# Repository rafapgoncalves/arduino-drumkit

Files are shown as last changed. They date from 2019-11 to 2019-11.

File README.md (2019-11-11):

# arduino-drumkit

An Arduino Nano USB drumkit to play with, but not limited to, [Ubuntu Studio](https://ubuntustudio.org/) 18.04 and [Hydrogen](http://hydrogen-music.org/) 0.9.7.

## Getting Started

1. Download and install Eclipse C/C++. More on that [here](https://www.eclipse.org/community/eclipse_newsletter/2017/april/article4.php);
2. Clone the repository;
3. Open eclipse and create a new workspace;
4. Go to File -> Import -> General -> Existing projects into workspace;
    - Select arduino-drumkit folder and check "Search for nested projects";
    - Make sure all projects are selected and click Finish.

### Arduino

First thing to do is to adjust the code to your arduino's version. Open [arduino/src/drums/Drumkit.cpp](/arduino/src/drums/Drumkit.cpp). 
At the Drumkit constructor you will find the declaration of the sensors (`SwitchSensor` for pull-up switches and `PiezoSensor` for piezos) and keys ([instructions](/KEYS.md)) for each drum pad.

Since I'm using Arduino Nano, the project is set up with 2 switches (one for bass drum and the other for hi-hat pedal) and 8 piezos.

You can change most of the parameters in [arduino/src/Define.h](/arduino/src/Define.h).

#### General MIDI

A few adjustments may be necessary to use it as a GM-compatible instrument:

* Make sure DEBUG messages are disabled;
* Keys may vary as stated [before](/KEYS.md);
* Baud Rate may be different, probably 31250.

### Ubuntu Studio

In order to run ubuntu-studio project you are goint to need read permission on serial port. Run the program as sudo or add your user to dialout group or equivalent. Don't forget to log off and back in for the changes to take effect.

```sh
sudo usermod -a -G dialout username
```

If you want to build ubuntu-studio project yourself, you gonna need some libraries that are not installed by default.

```sh
sudo apt update
sudo apt install libgtk-3-dev libgtkmm-3.0-dev
```

### Hardware

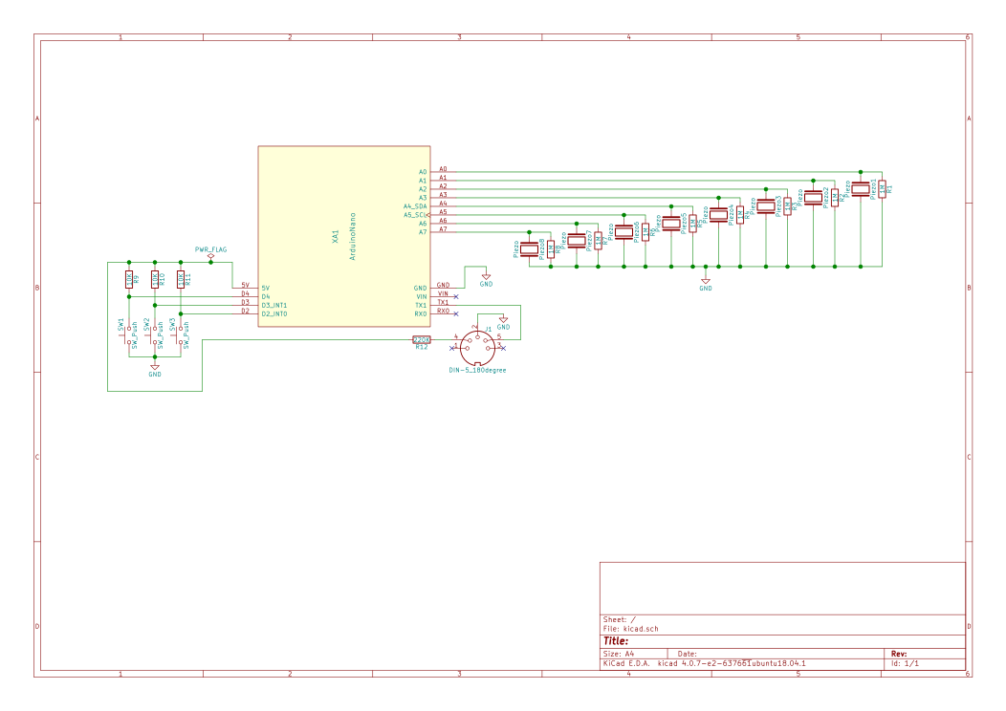
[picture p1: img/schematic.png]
Schematic


The DIN socket is optional in case you plan to use USB. And if you don't want to use USB, don't forget to add a power supply to Arduino.  

Threre is also a [KiCad](http://kicad-pcb.org/) project that you can use. This is a little bit out of scale and I didn't manage to track down where the problem is (footprint, KiCad, img conversion, etc) so double check before creating your pcb (I resized the final image). Also, your DIN socket will be different than mine.

There are good tutorials on YouTube to make drum pads such as [this](https://www.youtube.com/watch?v=-4BPpfFGcIE) one from Spikenzie.

### Jack Control

Connect your arduino to the PC, open and start ubuntu-studio project.

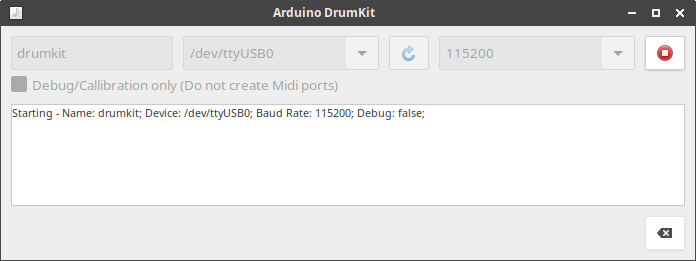
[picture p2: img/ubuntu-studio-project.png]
Ubuntu Studio Project


Open QjackCtl and Hydrogen.
On QjackCtl click the Connections button and go to ALSA tab. Connect arduino output port to hydrogen input port.

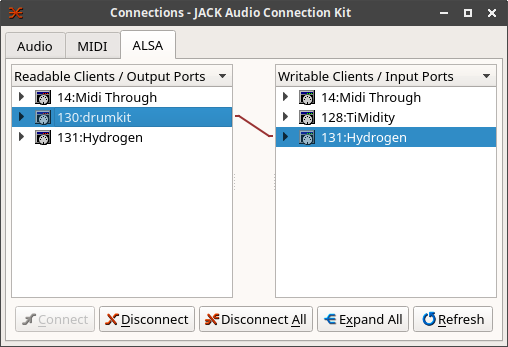
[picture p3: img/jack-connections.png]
Jack Connections


On Hydrogen, make sure input mode is set to Drumkit: Tools -> Input Mode -> Drumkit.

## License

This project is licensed under the GNU GENERAL PUBLIC LICENSE - see the [LICENSE](https://github.com/rafapgoncalves/arduino-drumkit/blob/master/LICENSE) file for details.

## Acknowledgments

* [evankale](https://github.com/evankale/ArduinoMidiDrums)
* [Dominique Vandenneucker](http://www.music-software-development.com/midi-tutorial.html)
* [amandaghassaei](https://www.instructables.com/id/Send-and-Receive-MIDI-with-Arduino/)
* [Thiago Teixeira & Jari Suominen](http://www.varal.org/ttymidi/)

## TODO

* Add MIDI Channel support
* Move debug messages to MIDI format

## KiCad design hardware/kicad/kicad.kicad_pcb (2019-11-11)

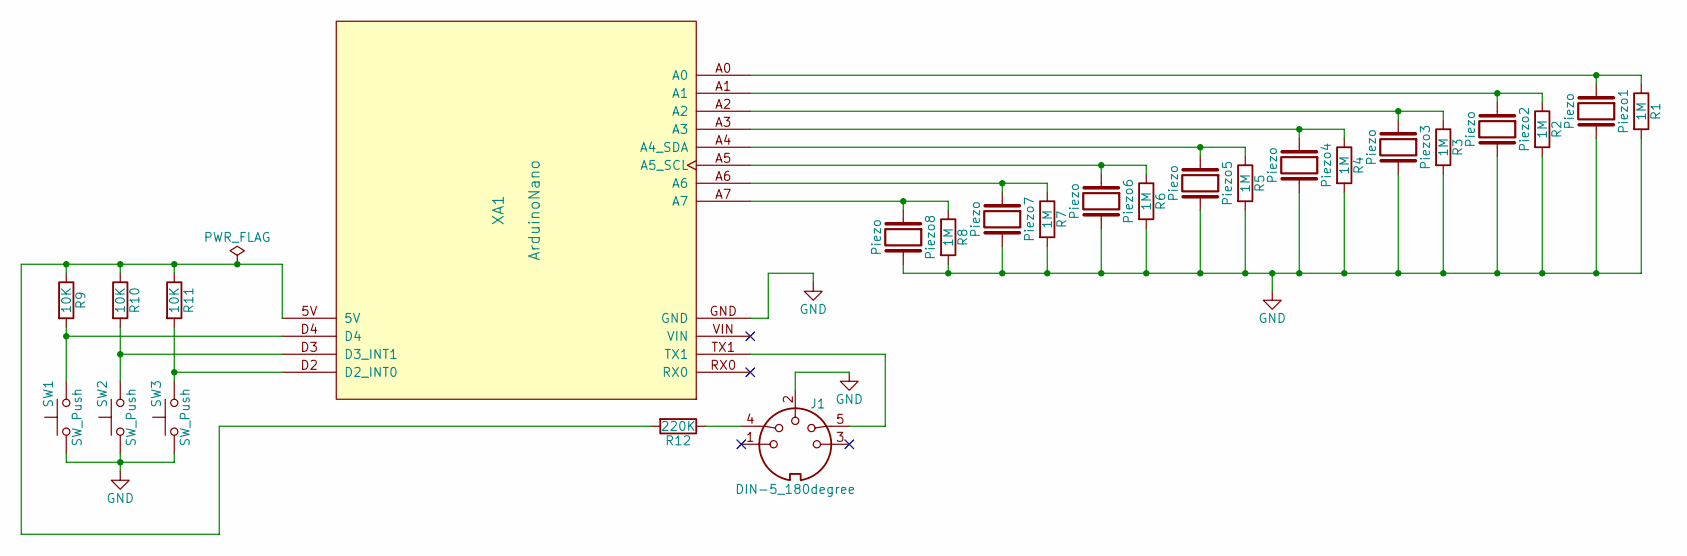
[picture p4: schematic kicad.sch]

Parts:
J1: DIN-5_180degree; Din5-180
Piezo1, Piezo2, Piezo3, Piezo4, Piezo5, Piezo6, Piezo7, Piezo8: Piezo; External_2_14.224mm
R1, R2, R3, R4, R5, R6, R7, R8: 1M; R_L6.22mm_D2.3mm_P10.16mm_Horizontal
R9, R10, R11: 10K; R_L6.22mm_D2.3mm_P10.16mm_Horizontal
R12: 220K; R_L6.22mm_D2.3mm_P10.16mm_Horizontal
SW1, SW2, SW3: SW_Push; External_2_14.224mm
XA1: ArduinoNano; ArduinoNanoJacks

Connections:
GND: J1.2, Piezo1.2, Piezo2.2, Piezo3.2, Piezo4.2, Piezo5.2, Piezo6.2, Piezo7.2, Piezo8.2, R1.2, R2.2, R3.2, R4.2, R5.2, R6.2, R7.2, R8.2, SW1.1, SW2.1, SW3.1, XA1.GND
unnamed: J1.4, R12.1
unnamed: J1.5, XA1.TX1
unnamed: Piezo1.1, R1.1, XA1.A0
unnamed: Piezo2.1, R2.1, XA1.A1
unnamed: Piezo3.1, R3.1, XA1.A2
unnamed: Piezo4.1, R4.1, XA1.A3
unnamed: Piezo5.1, R5.1, XA1.A4 (A4_SDA)
unnamed: Piezo6.1, R6.1, XA1.A5 (A5_SCL)
unnamed: Piezo7.1, R7.1, XA1.A6
unnamed: Piezo8.1, R8.1, XA1.A7
unnamed: R9.2, SW1.2, XA1.D4
unnamed: R9.1, R10.1, R11.1, R12.2, XA1.5V
unnamed: R10.2, SW2.2, XA1.D3 (D3_INT1)
unnamed: R11.2, SW3.2, XA1.D2 (D2_INT0)

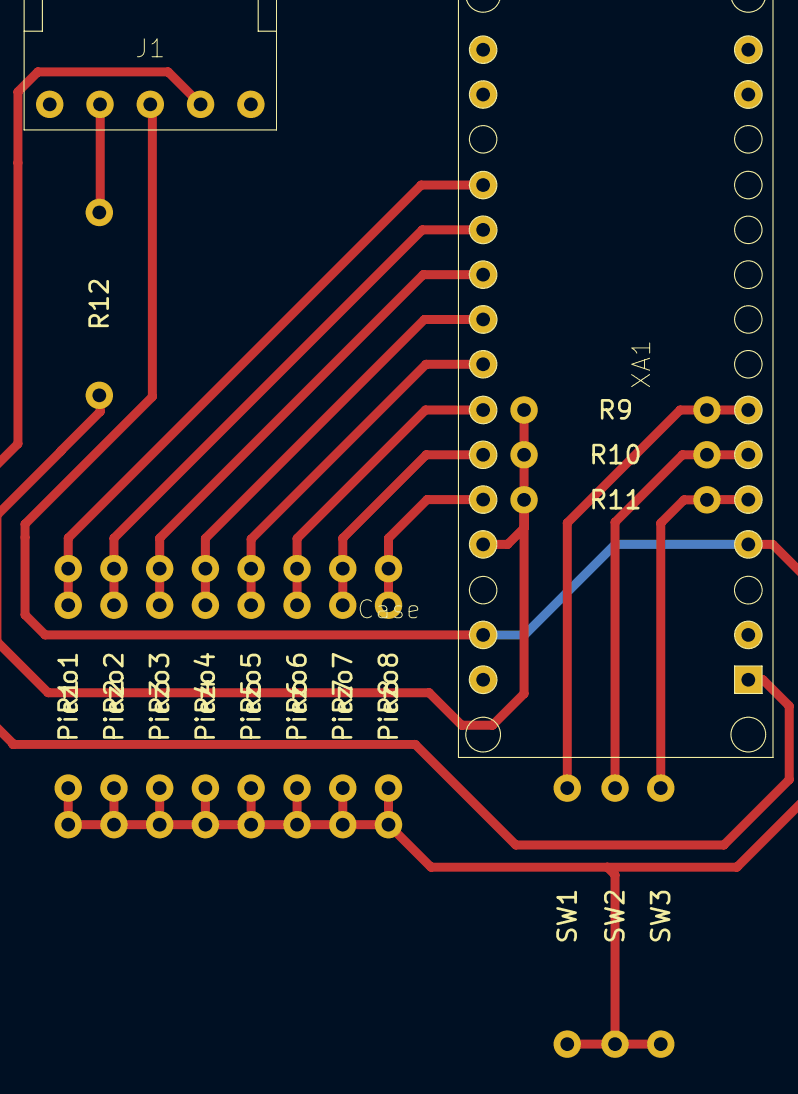
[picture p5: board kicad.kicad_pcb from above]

Board: 2 copper layers, 26 parts (0 on the bottom side), 15 nets.

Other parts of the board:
Case: Case

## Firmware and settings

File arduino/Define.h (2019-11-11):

/*
Copyright (c) 2019 rafapgoncalves.

This file is part of arduino-drumkit
(see https://github.com/rafapgoncalves/arduino-drumkit).

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
You should have received a copy of the GNU General Public License
along with this program. If not, see <http://www.gnu.org/licenses/>.
*/
#include <Arduino.h>

#ifndef DEFINE_H_
#define DEFINE_H_

#define BAUD_RATE 115200

#define DISABLE_DEBUG
#define DEBUG_COMMAND 112

// How much time to refuse consecutive notes
#define THROTTLING_MS 200
// How much time to read before decide velocity
#define PIEZO_SAMPLE_MS 20
// How much time to keep a higher threshold
#define PIEZO_HIGHER_THRESHOLD_MS 50


#define NOTE_ON 144
#define NOTE_OFF 128
#define MIN_VELOCITY 1
#define MAX_VELOCITY 127

#define LINEAR_VELOCITY_STEP 7

#define BASS_DRUM_PIN 2
#define BASS_DRUM_KEY 36
#define BASS_DRUM_FIXED_VELOCITY 75

#define FLOOR_TOM_PIN A7
#define FLOOR_TOM_KEY 41
#define FLOOR_TOM_THRESHOLD 35

#define SNARE_PIN A3
#define SNARE_KEY 38
#define SNARE_THRESHOLD 35

#define RACK_TOM_2_PIN A4
#define RACK_TOM_2_KEY 43
#define RACK_TOM_2_THRESHOLD 35

#define RACK_TOM_1_PIN A1
#define RACK_TOM_1_KEY 45
#define RACK_TOM_1_THRESHOLD 35

#define HI_HAT_PEDAL_PIN 3
#define HI_HAT_PEDAL_KEY 44
#define HI_HAT_PEDAL_FIXED_VELOCITY 75

#define HI_HAT_CYMBAL_PIN A2
#define HI_HAT_CYMBAL_CLOSED_KEY 42
#define HI_HAT_CYMBAL_OPEN_KEY 46
#define HI_HAT_CYMBAL_THRESHOLD 35

#define RIDE_CYMBAL_PIN A5
#define RIDE_CYMBAL_KEY 48
#define RIDE_CYMBAL_THRESHOLD 35

#define CRASH_CYMBAL_PIN A0
#define CRASH_CYMBAL_KEY 49
#define CRASH_CYMBAL_THRESHOLD 35

#define SPLASH_CYMBAL_PIN A6
#define SPLASH_CYMBAL_KEY 51
#define SPLASH_CYMBAL_THRESHOLD 35

// Constants
const int PRESSED = LOW;
const int RELEASED = HIGH;

#endif /* DEFINE_H_ */

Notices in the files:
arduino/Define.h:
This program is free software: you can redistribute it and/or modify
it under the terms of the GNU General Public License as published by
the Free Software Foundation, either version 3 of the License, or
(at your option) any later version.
